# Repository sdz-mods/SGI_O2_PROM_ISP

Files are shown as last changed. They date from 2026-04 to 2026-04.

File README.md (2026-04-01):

# SGI O2 PROM ISP

In-system programmer for the SGI O2 system PROM. It which allows writing/dumping the system PROM via USB. This can be done at any point, with the system on or off.
Mechanically compatible with all O2 CPU modules.

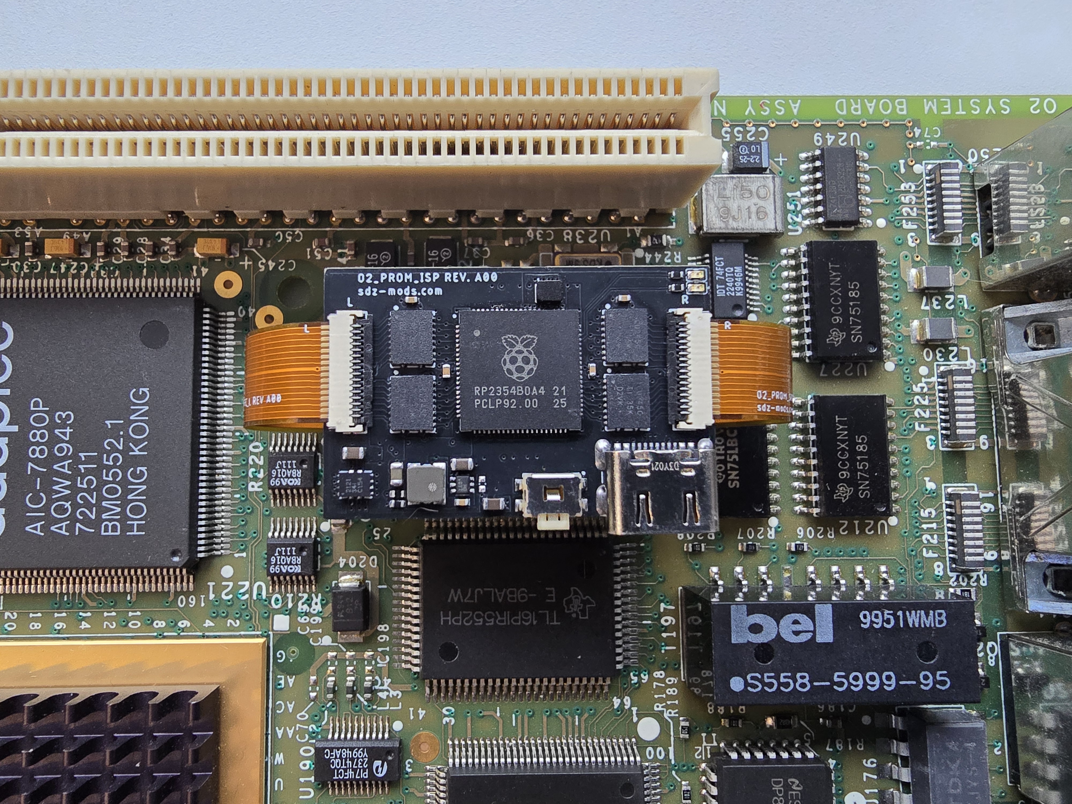
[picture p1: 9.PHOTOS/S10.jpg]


## Installation instructions:

-remove Dallas socket

-remove flash IC

-solder the two FFCs

-solder Dallas socket back

-install Dallas IC

-solder the flash IC to the ISP

-mount ISP on top of Dallas IC, connect the two FFCs.

### Flashing/dumping PROM

```csh
python3 O2_FLASH_PROM.py --port COM38 --flash IP32_418_dump.bin --verify

Opening port: COM38

File : IP32_418_dump.bin  (524,288 bytes)

Flash: 524,288 bytes  |  Chunks: 128 × 4096 bytes

Flashing...

Flashing: [########################################] 100%

Flash complete.

Verifying...

Verifying: [########################################] 100%

Verify passed — flash contents match file.

python3 O2_FLASH_PROM.py --port /dev/ttyUSB0 --dump testdump.bin

Opening port: /dev/ttyUSB0

Dumping 524,288 bytes to: testdump.bin

Dumping: [########################################] 100%

Dump complete. Saved 524,288 bytes to 'testdump.bin'
```

## Contents

1.SCH_BRD - contains editable schematic and board files. Format is Eagle CAD, but they can be imported in other tools, like Kicad.

2.SCH_PDF- schematics in pdf format.

3.P&P - pick and place files

4.BOM

5.GERBER - gerber files

6.FIRMWARE - pre-built firmware to be flashed on the RP2040

7.FIRMWARE_SRC - firmware source code plus support files.

8.HOST_TOOL - host flashing script

9.PHOTOS - installation photos

## Notes

-There is a very high probabilty if you install this and flash a firmware, you won't be able to setenv -p or resetenv from PROM. This isn't related to the ISP, it happens even when swapping the flash ICs between two working motherboards.

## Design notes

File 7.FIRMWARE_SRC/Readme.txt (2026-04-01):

Built with:
cmake version 3.31.5
ninja version 1.12.1
arm-none-eabi-gcc version 14.2.1
Pico SDK 2.2.0

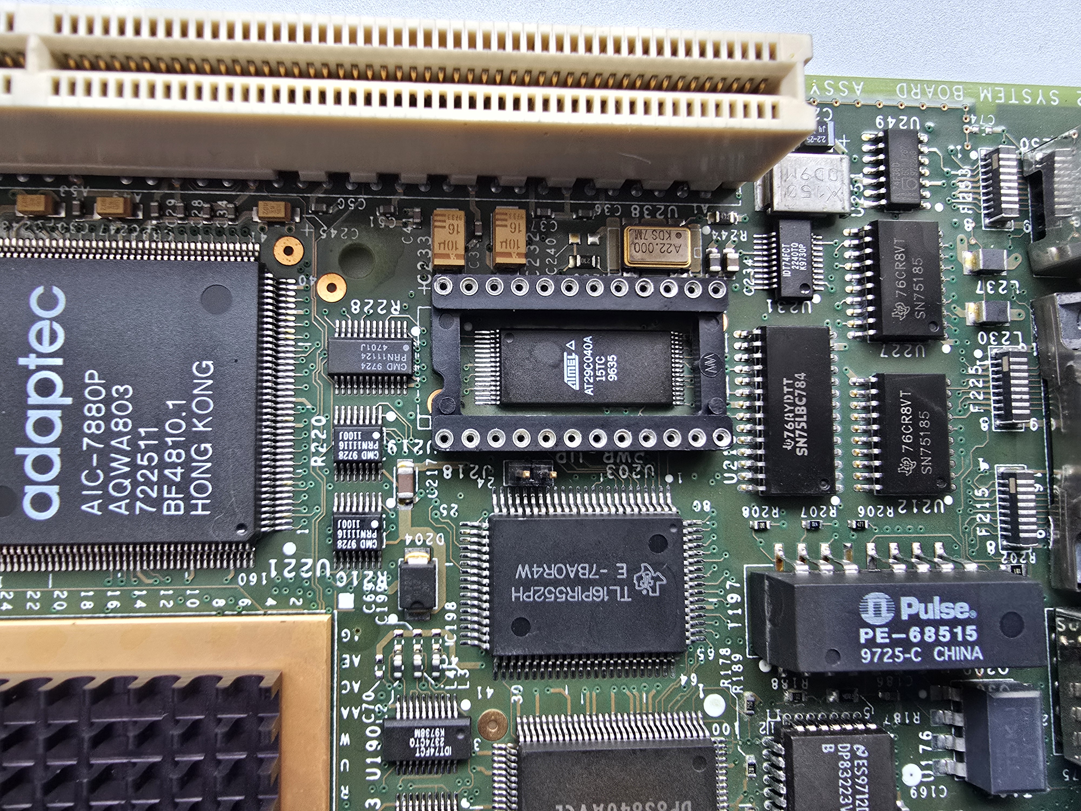
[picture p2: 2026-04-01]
9.PHOTOS/S2.jpg

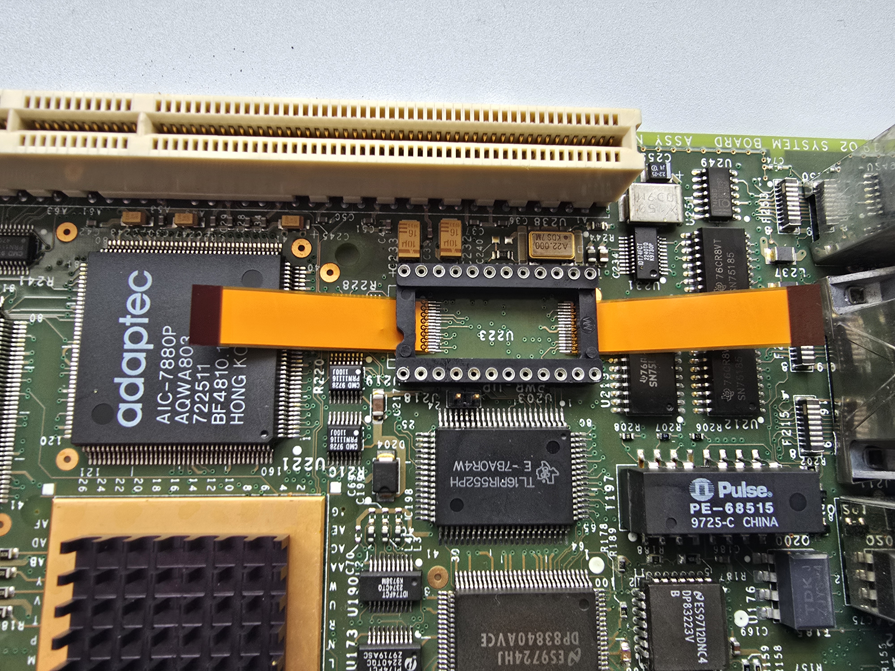
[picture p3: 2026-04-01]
9.PHOTOS/S6.jpg

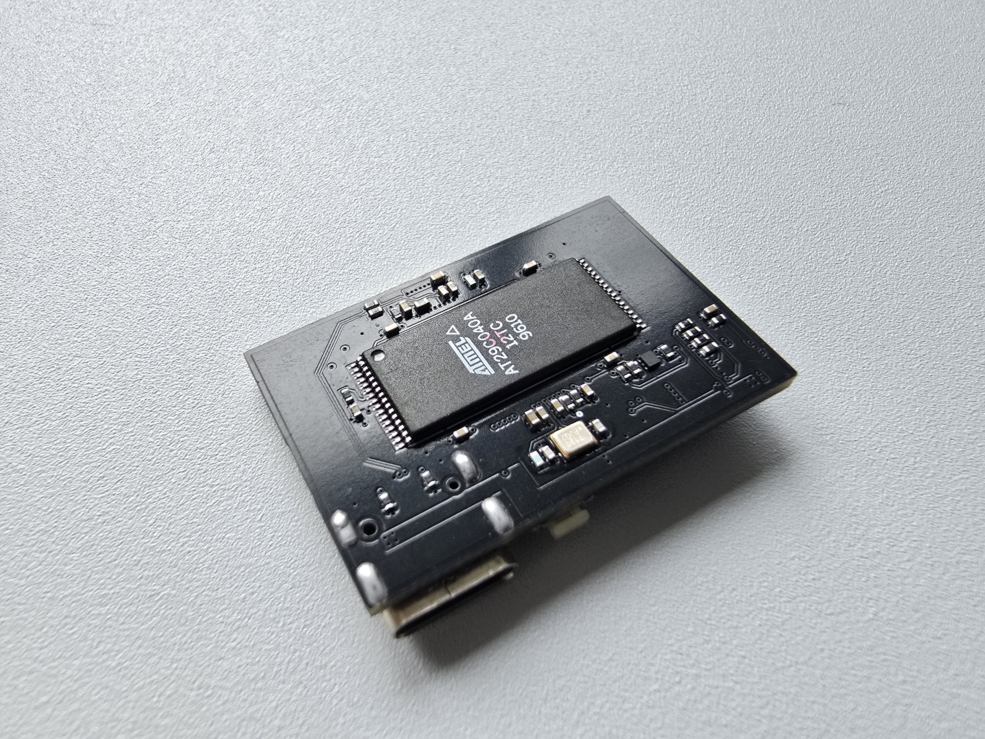
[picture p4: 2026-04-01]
9.PHOTOS/S9.jpg

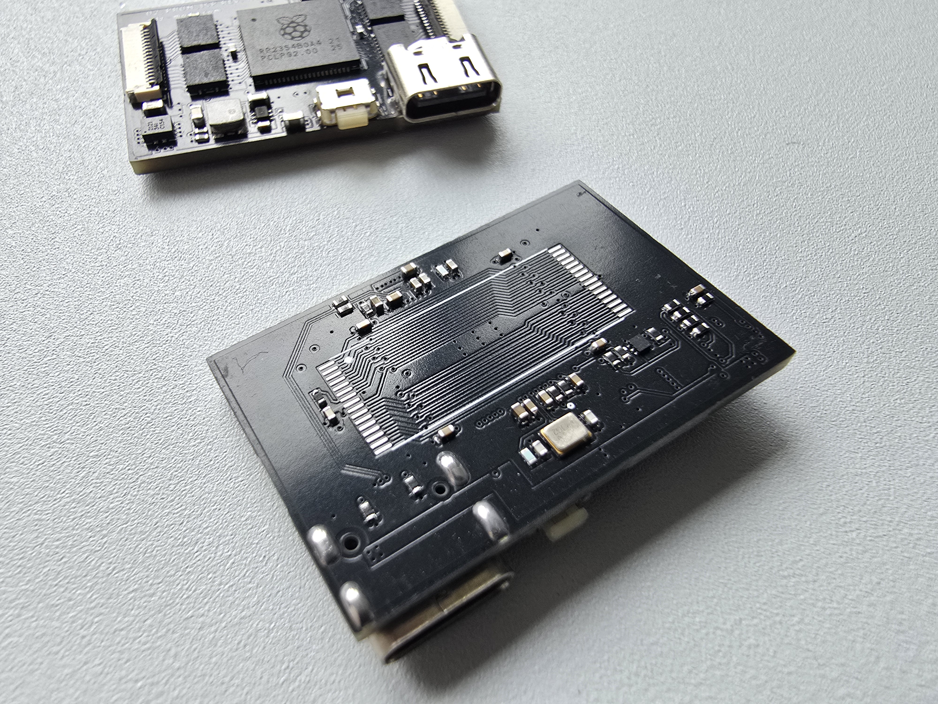
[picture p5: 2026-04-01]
9.PHOTOS/S8.jpg

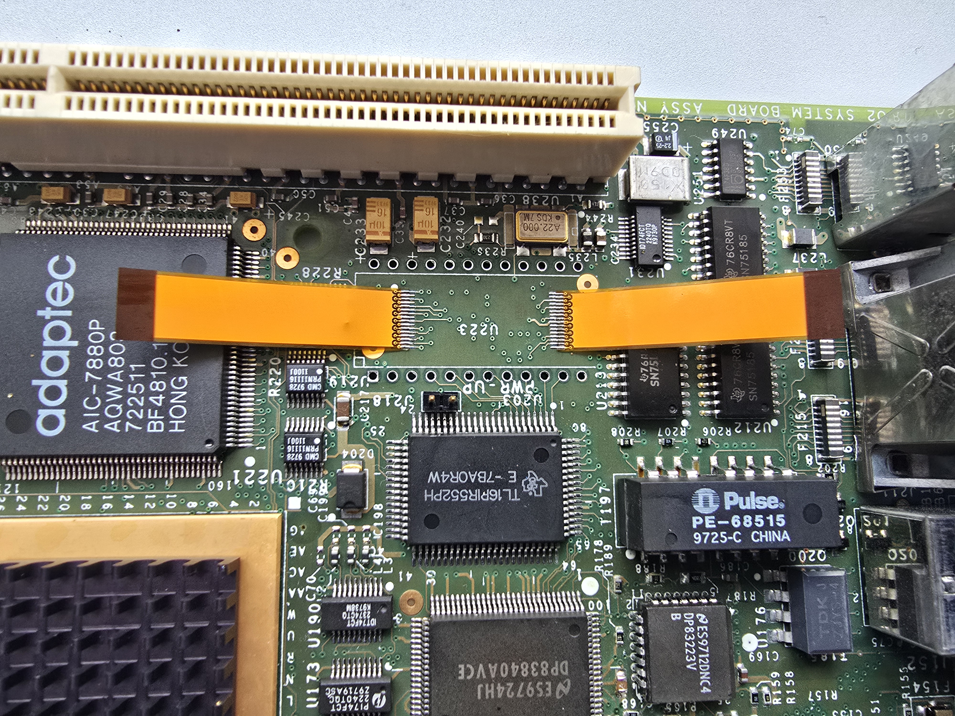
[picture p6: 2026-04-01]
9.PHOTOS/S5.jpg

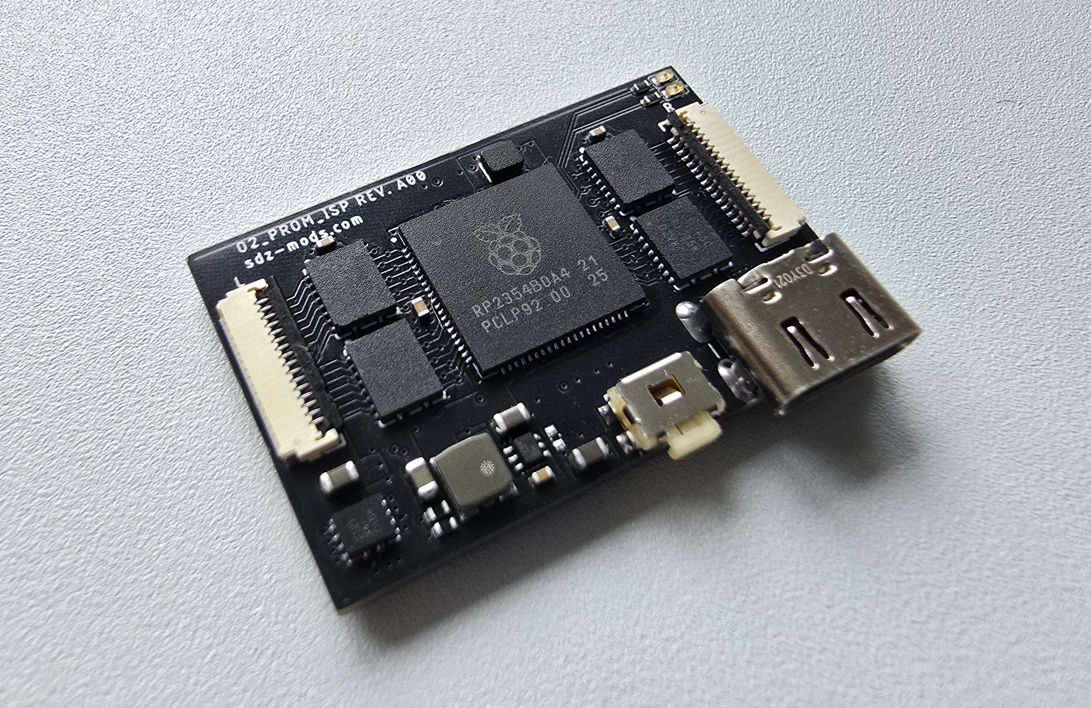
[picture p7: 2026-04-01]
9.PHOTOS/S0.jpg

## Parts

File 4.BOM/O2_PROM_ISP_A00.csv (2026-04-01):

Qty | Value | Device | Package | Parts | Description | CONTACT-RESISTANCE | DATASHEET-URL | DESCRIPTION | HEIGHT | IR | L | MANUFACTURER_NAME | MANUFACTURER_PART_NUMBER | MOUSER_PART_NUMBER | MOUSER_PRICE-STOCK | PACKAGING | PART-NUMBER | PINS | PITCH | TYPE | VALUE | WORKING-VOLTAGE
1 |  | 434353045816 | 434353045816 | S3 | 3.5x4.7 mm SMD J-Bend side push WS-TASU
1 | 10.2kR | RESISTOR0402D | 0402D | R9 | Resistors
16 | 100nF 25V | CAP_CERAMIC0402D | 0402D | C1, C5, C8, C9, C10, C15, C16, C17, C18, C29, C30, C31, C33, C34, C37, C114 | Ceramic Capacitors
8 | 10kR | RESISTOR0402D | 0402D | R2, R11, R12, R13, R14, R15, R16, R100 | Resistors
3 | 10uF 16V | CAP_CERAMIC0603D | 0603D | C2, C3, C4 | Ceramic Capacitors
1 | 18kR | RESISTOR0402D | 0402D | R8 | Resistors
2 | 1kR | RESISTOR0402D | 0402D | R3, R4 | Resistors
2 | 220R | RESISTOR0402D | 0402D | R97, R98 | Resistors
2 | 22R | RESISTOR0402D | 0402D | R5, R6 | Resistors
1 | 22uF 6.3V | CAP_CERAMIC0603D | 0603D | C6 | Ceramic Capacitors
1 | 31.6kR | RESISTOR0402D | 0402D | R1 | Resistors
1 | 33R | RESISTOR0402D | 0402D | R7 | Resistors
2 | 33pF 25V C0G | CAP_CERAMIC0402D | 0402D | C12, C13 | Ceramic Capacitors
5 | 4.7uF 6.3V | CAP_CERAMIC0402D | 0402D | C14, C32, C35, C36, C38 | Ceramic Capacitors
1 | 44.2kR | RESISTOR0402D | 0402D | R105 | Resistors
2 | 5.1kR | RESISTOR0402D | 0402D | R37, R38 | Resistors
1 | 5kR | RESISTOR0402D | 0402D | R10 | Resistors
2 | 687116182122 | 6871XX182122_687116182122 | 687116182122 | J1, J2 | WR-FPC 0.50 mm SMT ZIF Horizontal Dual Contact | 30mOhm | https://www.we-online.com/redexpert/spec/687116182122?ae |  |  | 0.5A | 10mm |  |  |  |  | Tape and Reel | 687116182122 | 16 | 0.5mm | Horizontal | 687116182122 | 50V(AC)
1 | 8Z-12.000MAAJ-T | TXC-8Z-25X20 | TXC-8Z-25X20 | Y2
1 | AOTA-B201610S3R3-101-T | AOTA-B201610S3R3-101-T | 0806 | L2
1 | AP62250Z6-7 | AP62250Z6-7 | SOTFL50P160X60-6N | U5 | Switching Voltage Regulators DCDC Conv HV Buck SOT563 T&R 3K |  |  | Switching Voltage Regulators DCDC Conv HV Buck SOT563 T&R 3K | 0.6mm |  |  | Diodes Inc. | AP62250Z6-7 | 621-AP62250Z6-7 | https://www.mouser.co.uk/ProductDetail/Diodes-Incorporated/AP62250Z6-7?qs=7MVldsJ5UazFBrGnyLje6A%3D%3D
1 | AT29C040A-12TC";AT29C040A-12TC"" | TSOP32_8X20 | U1
1 | DNP | CAP_CERAMIC0402D | 0402D | C7 | Ceramic Capacitors
1 | DX07S016JA3R1500 | DX07S016JA3R1500 | DX07S016JA3R1500 | J4
2 | ORANGE | LED | CHIPLED_0402C | LED5, LED6 | LED
1 | PMDXB600UNEZ | PMDXB600UNEZ | PMDXB600UNEZ | Q3 | PMDXB600UNEZ Hex N-Channel MOSFET, 600 mA, 20 V, 8-Pin DFN1010B-6, SOT1216 Nexperia |  |  | PMDXB600UNEZ Hex N-Channel MOSFET, 600 mA, 20 V, 8-Pin DFN1010B-6, SOT1216 Nexperia | 0.4mm |  |  | Nexperia | PMDXB600UNEZ | 771-PMDXB600UNEZ | https://www.mouser.co.uk/ProductDetail/Nexperia/PMDXB600UNEZ/?qs=gNSudQoqUYA4PlgBT4gR6w%3D%3D
1 | SC1512 | SC1512 | SC1512 | U$35
4 | SN74CBT3245CRGYR | SN74CBT3245CRGYR | VQFN-20 | U9, U10, U11, U12
1 | TPS2121RUX | TPS2121RUX | VQFN-HR-12 | U2
1 | VLS3012HBX-2R2M | VLS3012HBX-2R2M | VLS3012 | L3 | Fixed Inductors 3x3x1.2mm 2.2uH 20% Magnetic Pwr Inductr |  |  | Fixed Inductors 3x3x1.2mm 2.2uH 20% Magnetic Pwr Inductr | mm |  |  | TDK | VLS3012HBX-2R2M | 810-VLS3012HBX-2R2M | https://www.mouser.co.uk/ProductDetail/TDK/VLS3012HBX-2R2M?qs=pfd5qewlna6oSgcfnWnTMg%3D%3D

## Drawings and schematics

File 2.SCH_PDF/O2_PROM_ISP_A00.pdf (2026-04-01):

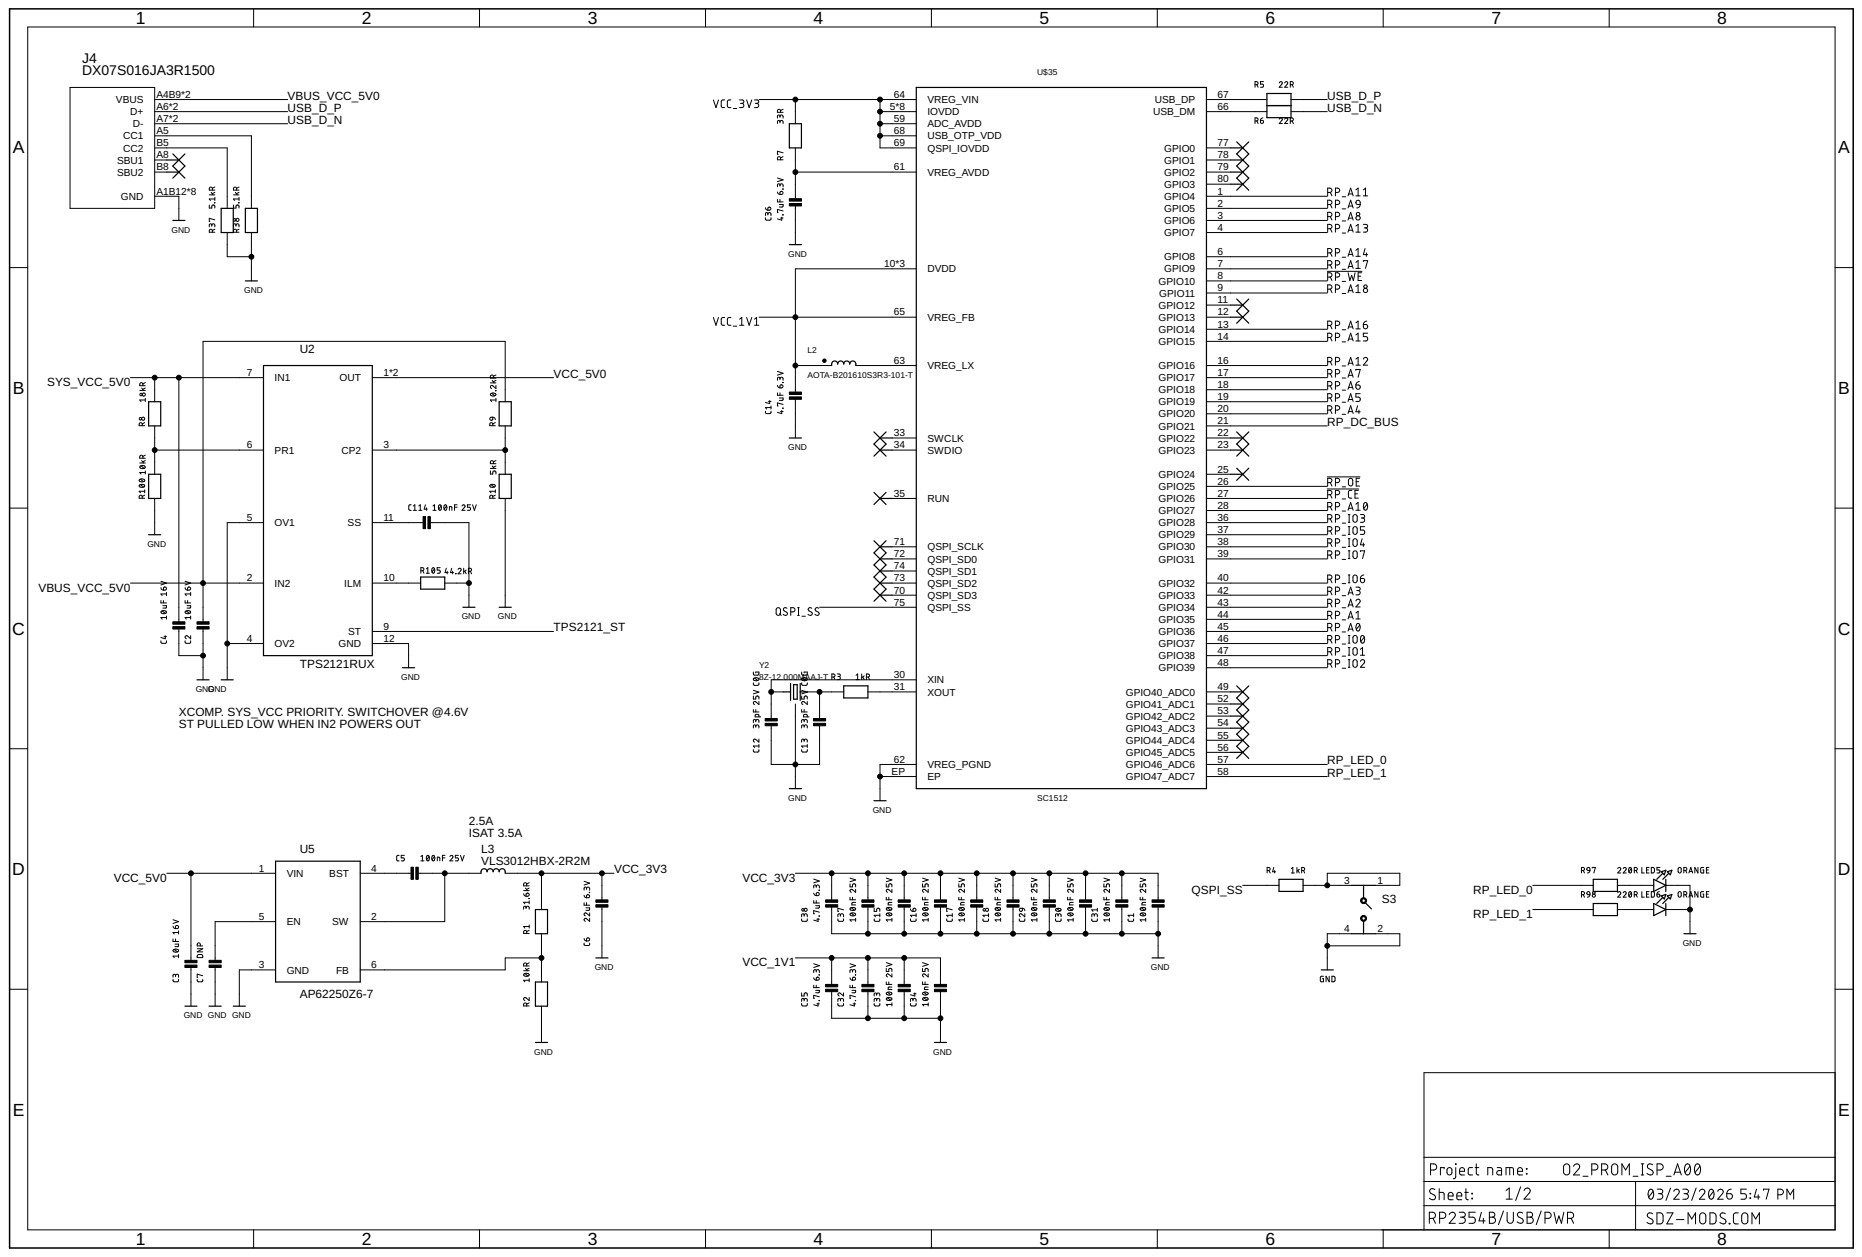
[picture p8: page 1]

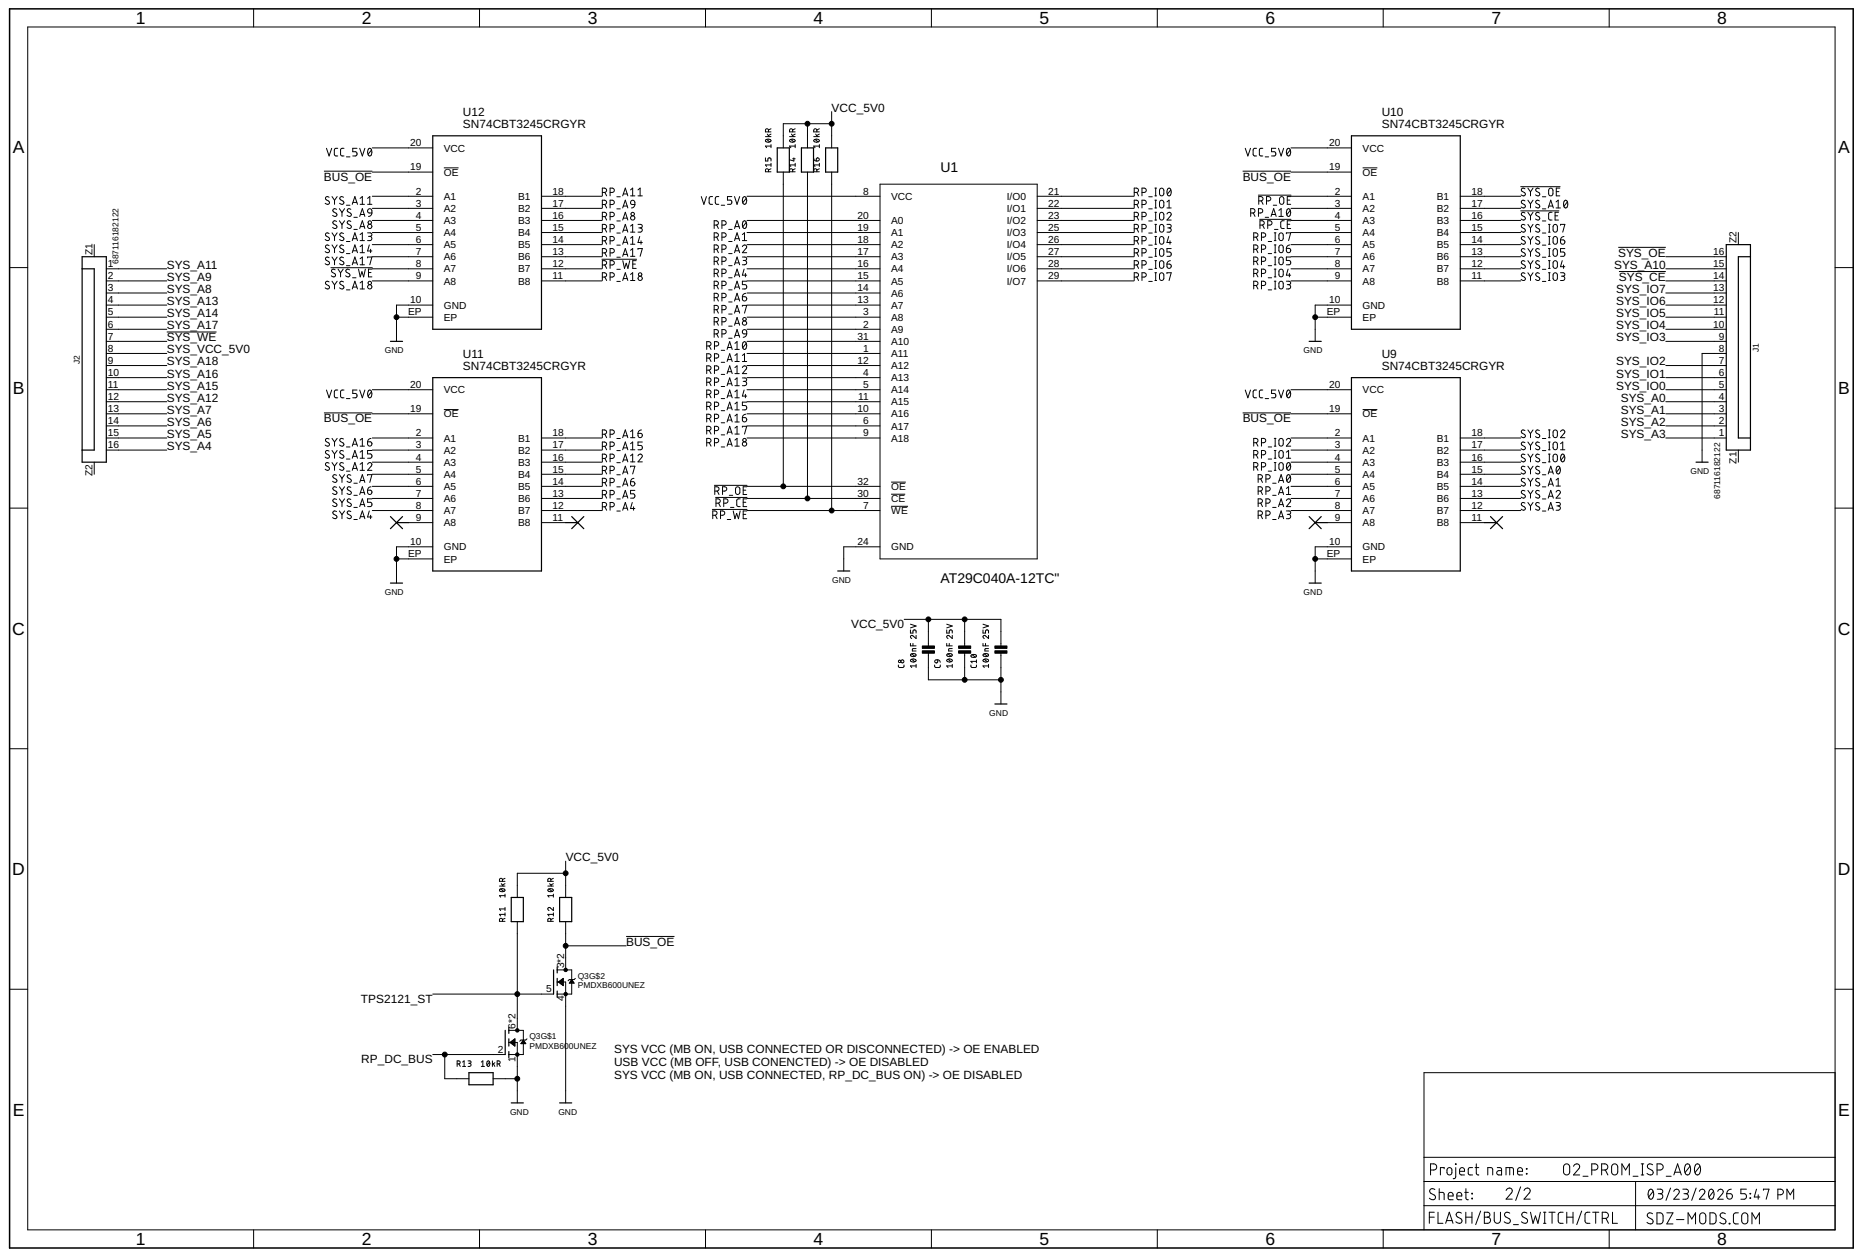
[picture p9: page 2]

VCC_5V0

SYS VCC (MB ON, USB CONNECTED OR DISCONNECTED) -> OE ENABLED
USB VCC (MB OFF, USB CONENCTED) -> OE DISABLED
SYS VCC (MB ON, USB CONNECTED, RP_DC_BUS ON) -> OE DISABLED

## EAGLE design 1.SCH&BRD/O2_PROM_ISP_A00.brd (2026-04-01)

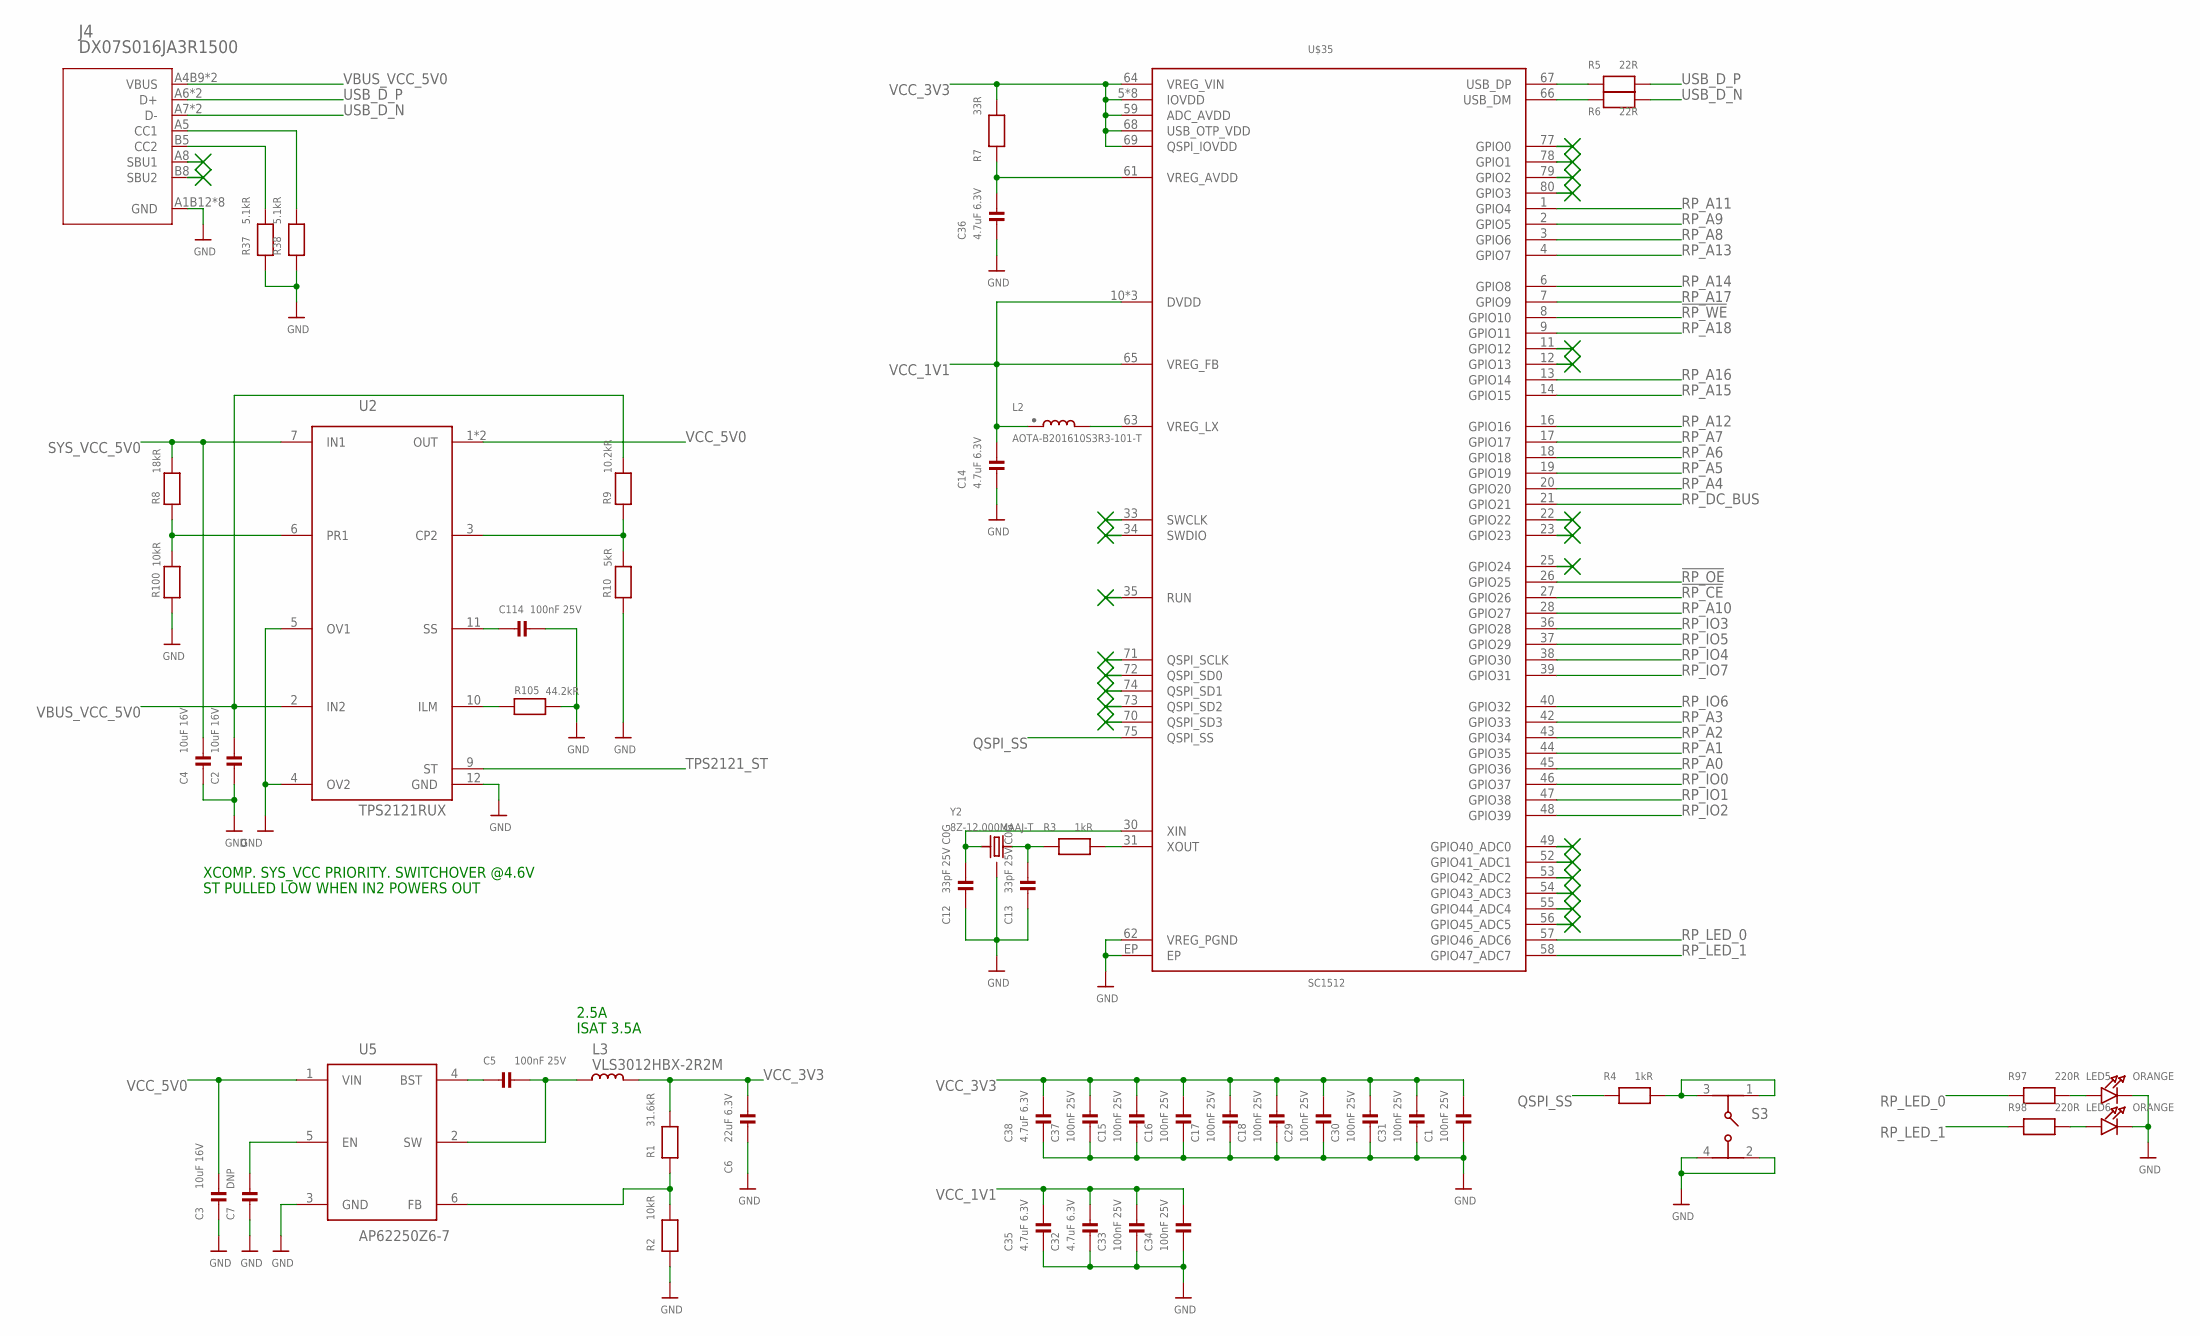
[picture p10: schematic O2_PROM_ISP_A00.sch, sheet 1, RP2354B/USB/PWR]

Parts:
C1, C5, C15, C16, C17, C18, C29, C30, C31, C33, C34, C37, C114: 100nF 25V; 0402D
C2, C3, C4: 10uF 16V; 0603D
C6: 22uF 6.3V; 0603D
C7: DNP; 0402D
C12, C13: 33pF 25V C0G; 0402D
C14, C32, C35, C36, C38: 4.7uF 6.3V; 0402D
J4: DX07S016JA3R1500
L2: AOTA-B201610S3R3-101-T; 0806
L3: VLS3012HBX-2R2M; VLS3012
LED5, LED6: ORANGE; CHIPLED_0402C
R1: 31.6kR; 0402D
R2, R100: 10kR; 0402D
R3, R4: 1kR; 0402D
R5, R6: 22R; 0402D
R7: 33R; 0402D
R8: 18kR; 0402D
R9: 10.2kR; 0402D
R10: 5kR; 0402D
R37, R38: 5.1kR; 0402D
R97, R98: 220R; 0402D
R105: 44.2kR; 0402D
S3: 434353045816
U2: TPS2121RUX; VQFN-HR-12
U5: AP62250Z6-7; SOTFL50P160X60-6N
U$35: SC1512
Y2: 8Z-12.000MAAJ-T; TXC-8Z-25X20

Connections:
!RP_CE: U$35.27 (GPIO26); also elsewhere on the board
!RP_OE: U$35.26 (GPIO25); also elsewhere on the board
!RP_WE: U$35.8 (GPIO10); also elsewhere on the board
GND: C1.3, C2.2, C3.2, C4.2, C6.2, C7.4, C12.3, C13.3, C14.3, C15.3, C16.3, C17.3, C18.3, C29.3, C30.3, C31.3, C32.3, C33.3, C34.3, C35.3, C36.3, C37.3, C38.3, C114.3, J4.A1B12 (GND), J4.A12/B1 (GND), J4.MH1 (GND), J4.MH2 (GND), J4.MH3 (GND), J4.MH4 (GND), J4.MP1 (GND), J4.MP2 (GND), LED5.4 (C), LED6.4 (C), R2.4 (2), R10.3 (1), R37.3 (1), R38.3 (1), R100.3 (1), R105.4 (2), S3.2 (4), S3.4 (2), U2.4 (OV2), U2.5 (OV1), U2.12 (GND), U5.3 (GND), U$35.62 (VREG_PGND), U$35.EP, Y2.2 (GND), Y2.4 (GND); also elsewhere on the board
unnamed: J4.A5 (CC1), R38.4 (2)
unnamed: R9.3 (1), R10.4 (2), U2.3 (CP2)
unnamed: J4.B5 (CC2), R37.4 (2)
unnamed: LED5.3 (A), R97.3 (1)
unnamed: LED6.3 (A), R98.3 (1)
unnamed: C13.4, R3.3 (1), Y2.3 (2)
unnamed: C12.4, U$35.30 (XIN), Y2.1
unnamed: R3.4 (2), U$35.31 (XOUT)
unnamed: R4.4 (2), S3.1 (3), S3.3 (1)
unnamed: L2.2, U$35.63 (VREG_LX)
unnamed: C5.4, U5.4 (BST)
unnamed: C5.3, L3.1 (3), U5.2 (SW)
unnamed: R1.4 (2), R2.3 (1), U5.6 (FB)
unnamed: C7.3, U5.5 (EN)
unnamed: C36.4, R7.4 (2), U$35.61 (VREG_AVDD)
unnamed: C114.4, U2.11 (SS)
unnamed: R105.3 (1), U2.10 (ILM)
unnamed: R8.3 (1), R100.4 (2), U2.6 (PR1)
QSPI_SS: R4.3 (1), U$35.75 (QSPI_SS)
RP_A0: U$35.45 (GPIO36); also elsewhere on the board
RP_A1: U$35.44 (GPIO35); also elsewhere on the board
RP_A2: U$35.43 (GPIO34); also elsewhere on the board
RP_A3: U$35.42 (GPIO33); also elsewhere on the board
RP_A4: U$35.20 (GPIO20); also elsewhere on the board
RP_A5: U$35.19 (GPIO19); also elsewhere on the board
RP_A6: U$35.18 (GPIO18); also elsewhere on the board
RP_A7: U$35.17 (GPIO17); also elsewhere on the board
RP_A8: U$35.3 (GPIO6); also elsewhere on the board
RP_A9: U$35.2 (GPIO5); also elsewhere on the board
RP_A10: U$35.28 (GPIO27); also elsewhere on the board
RP_A11: U$35.1 (GPIO4); also elsewhere on the board
RP_A12: U$35.16 (GPIO16); also elsewhere on the board
RP_A13: U$35.4 (GPIO7); also elsewhere on the board
RP_A14: U$35.6 (GPIO8); also elsewhere on the board
RP_A15: U$35.14 (GPIO15); also elsewhere on the board
RP_A16: U$35.13 (GPIO14); also elsewhere on the board
RP_A17: U$35.7 (GPIO9); also elsewhere on the board
RP_A18: U$35.9 (GPIO11); also elsewhere on the board
RP_DC_BUS: U$35.21 (GPIO21); also elsewhere on the board
RP_IO0: U$35.46 (GPIO37); also elsewhere on the board
RP_IO1: U$35.47 (GPIO38); also elsewhere on the board
RP_IO2: U$35.48 (GPIO39); also elsewhere on the board
RP_IO3: U$35.36 (GPIO28); also elsewhere on the board
RP_IO4: U$35.38 (GPIO30); also elsewhere on the board
RP_IO5: U$35.37 (GPIO29); also elsewhere on the board
RP_IO6: U$35.40 (GPIO32); also elsewhere on the board
RP_IO7: U$35.39 (GPIO31); also elsewhere on the board
RP_LED_0: R97.4 (2), U$35.57 (GPIO46_ADC6)
RP_LED_1: R98.4 (2), U$35.58 (GPIO47_ADC7)
SYS_VCC_5V0: C4.1, R8.4 (2), U2.7 (IN1); also elsewhere on the board
TPS2121_ST: U2.9 (ST); also elsewhere on the board
USB_D_C_N: R6.3 (1), U$35.66 (USB_DM)
USB_D_C_P: R5.3 (1), U$35.67 (USB_DP)
USB_D_N: J4.A7 (D-), J4.B7 (D-), R6.4 (2)
USB_D_P: J4.A6 (D+), J4.B6 (D+), R5.4 (2)
VBUS_VCC_5V0: C2.1, J4.A4B9 (VBUS), J4.B4A9 (VBUS), R9.4 (2), U2.2 (IN2)
VCC_1V1: C14.4, C32.4, C33.4, C34.4, C35.4, L2.1, U$35.10 (DVDD), U$35.32 (DVDD), U$35.51 (DVDD), U$35.65 (VREG_FB)
VCC_3V3: C1.4, C6.1, C15.4, C16.4, C17.4, C18.4, C29.4, C30.4, C31.4, C37.4, C38.4, L3.2 (4), R1.3 (1), R7.3 (1), U$35.5 (IOVDD), U$35.15 (IOVDD), U$35.24 (IOVDD), U$35.29 (IOVDD), U$35.41 (IOVDD), U$35.50 (IOVDD), U$35.59 (ADC_AVDD), U$35.60 (IOVDD), U$35.64 (VREG_VIN), U$35.68 (USB_OTP_VDD), U$35.69 (QSPI_IOVDD), U$35.76 (IOVDD)
VCC_5V0: C3.1, U2.1 (OUT), U2.8 (OUT), U5.1 (VIN); also elsewhere on the board

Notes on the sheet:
2.5A
ISAT 3.5A
XCOMP. SYS_VCC PRIORITY. SWITCHOVER @4.6V
ST PULLED LOW WHEN IN2 POWERS OUT

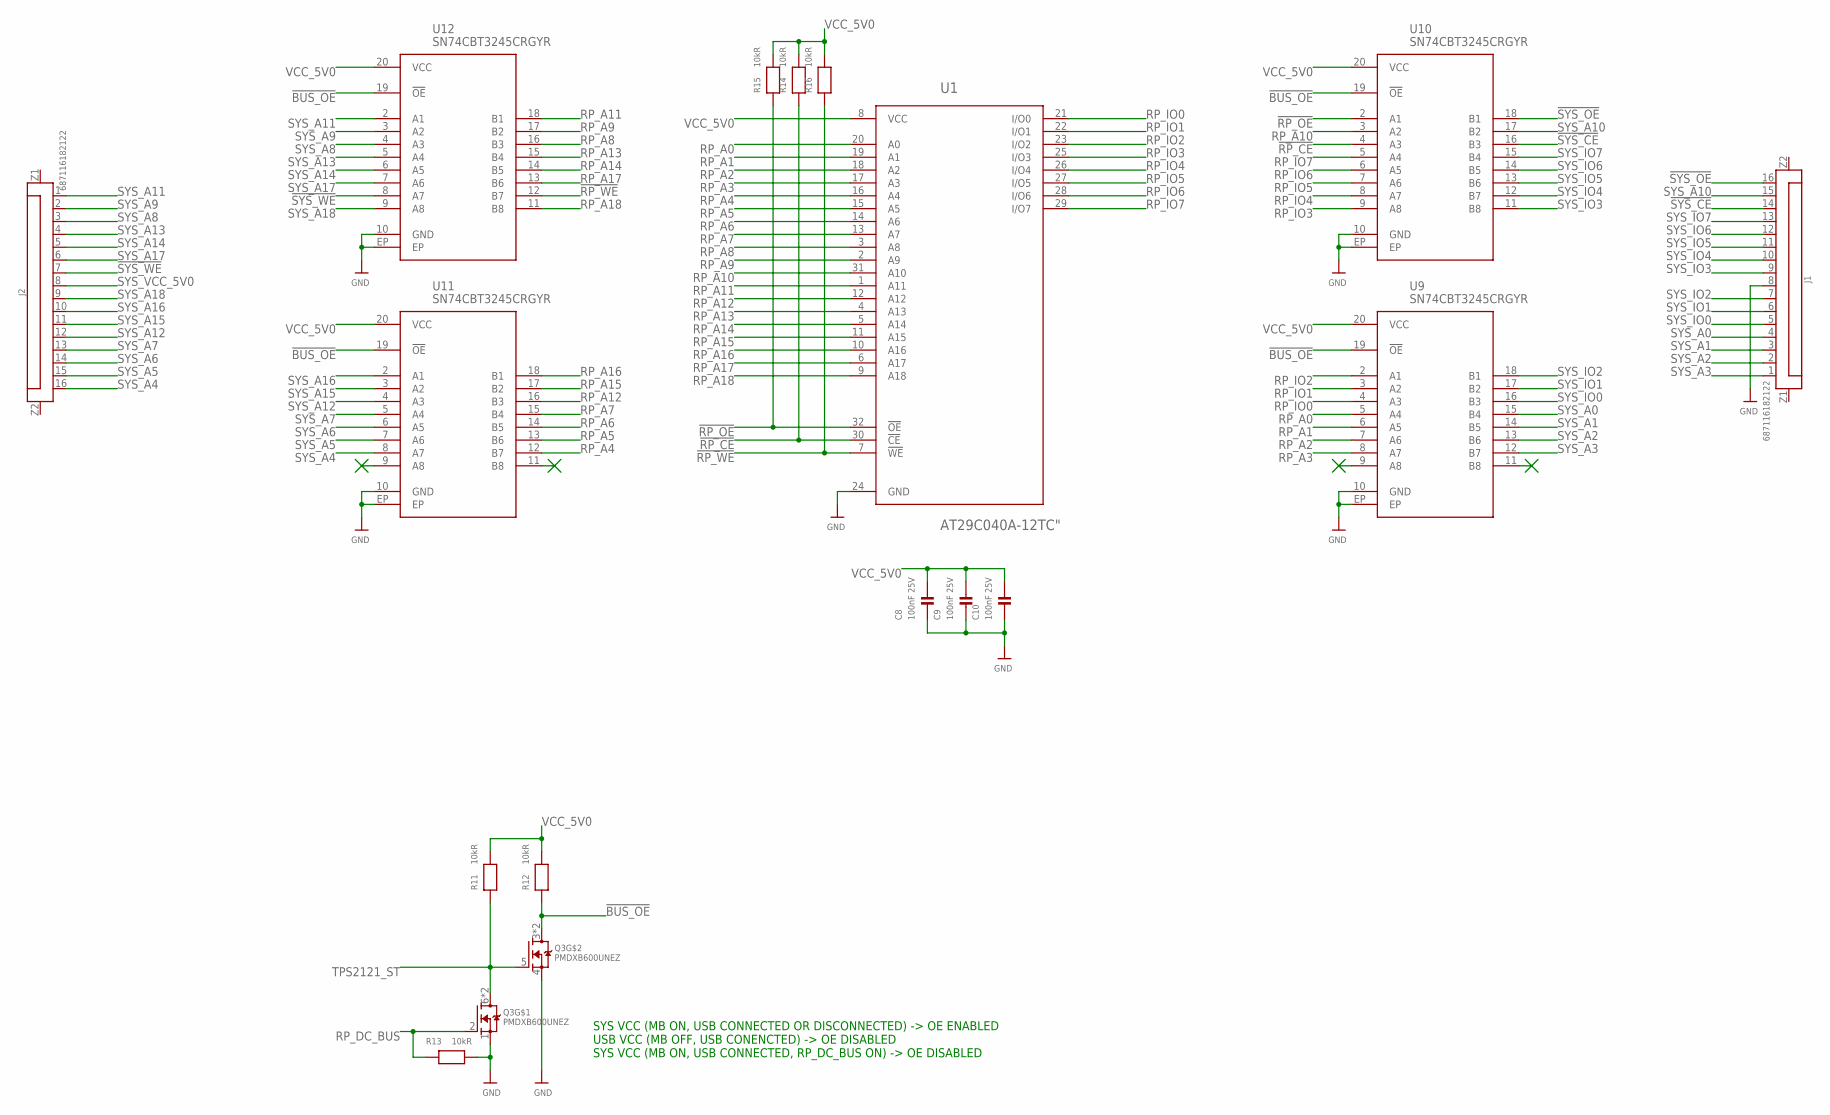
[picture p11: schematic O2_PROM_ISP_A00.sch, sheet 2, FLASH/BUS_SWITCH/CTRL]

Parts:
C8, C9, C10: 100nF 25V; 0402D
J1, J2: 687116182122
Q3: PMDXB600UNEZ
R11, R12, R13, R14, R15, R16: 10kR; 0402D
U1: AT29C040A-12TC"; TSOP32_8X20
U9, U10, U11, U12: SN74CBT3245CRGYR; VQFN-20

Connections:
!BUS_OE: Q3.3 (D), Q3.8 (D), R12.4 (2), U9.19 (!OE), U10.19 (!OE), U11.19 (!OE), U12.19 (!OE)
!RP_CE: R14.4 (2), U1.30 (!CE), U10.4 (A3); also elsewhere on the board
!RP_OE: R15.4 (2), U1.32 (!OE), U10.2 (A1); also elsewhere on the board
!RP_WE: R16.4 (2), U1.7 (!WE), U12.12 (B7); also elsewhere on the board
!SYS_CE: J1.14, U10.16 (B3)
!SYS_OE: J1.16, U10.18 (B1)
!SYS_WE: J2.7, U12.8 (A7)
GND: C8.3, C9.3, C10.3, J1.8, Q3.1 (S), Q3.4 (S), R13.3 (1), U1.24 (GND), U9.10 (GND), U9.EP, U10.10 (GND), U10.EP, U11.10 (GND), U11.EP, U12.10 (GND), U12.EP; also elsewhere on the board
RP_A0: U1.20 (A0), U9.5 (A4); also elsewhere on the board
RP_A1: U1.19 (A1), U9.6 (A5); also elsewhere on the board
RP_A2: U1.18 (A2), U9.7 (A6); also elsewhere on the board
RP_A3: U1.17 (A3), U9.8 (A7); also elsewhere on the board
RP_A4: U1.16 (A4), U11.12 (B7); also elsewhere on the board
RP_A5: U1.15 (A5), U11.13 (B6); also elsewhere on the board
RP_A6: U1.14 (A6), U11.14 (B5); also elsewhere on the board
RP_A7: U1.13 (A7), U11.15 (B4); also elsewhere on the board
RP_A8: U1.3 (A8), U12.16 (B3); also elsewhere on the board
RP_A9: U1.2 (A9), U12.17 (B2); also elsewhere on the board
RP_A10: U1.31 (A10), U10.3 (A2); also elsewhere on the board
RP_A11: U1.1 (A11), U12.18 (B1); also elsewhere on the board
RP_A12: U1.12 (A12), U11.16 (B3); also elsewhere on the board
RP_A13: U1.4 (A13), U12.15 (B4); also elsewhere on the board
RP_A14: U1.5 (A14), U12.14 (B5); also elsewhere on the board
RP_A15: U1.11 (A15), U11.17 (B2); also elsewhere on the board
RP_A16: U1.10 (A16), U11.18 (B1); also elsewhere on the board
RP_A17: U1.6 (A17), U12.13 (B6); also elsewhere on the board
RP_A18: U1.9 (A18), U12.11 (B8); also elsewhere on the board
RP_DC_BUS: Q3.2 (G), R13.4 (2); also elsewhere on the board
RP_IO0: U1.21 (I/O0), U9.4 (A3); also elsewhere on the board
RP_IO1: U1.22 (I/O1), U9.3 (A2); also elsewhere on the board
RP_IO2: U1.23 (I/O2), U9.2 (A1); also elsewhere on the board
RP_IO3: U1.25 (I/O3), U10.9 (A8); also elsewhere on the board
RP_IO4: U1.26 (I/O4), U10.8 (A7); also elsewhere on the board
RP_IO5: U1.27 (I/O5), U10.7 (A6); also elsewhere on the board
RP_IO6: U1.28 (I/O6), U10.6 (A5); also elsewhere on the board
RP_IO7: U1.29 (I/O7), U10.5 (A4); also elsewhere on the board
SYS_A0: J1.4, U9.15 (B4)
SYS_A1: J1.3, U9.14 (B5)
SYS_A2: J1.2, U9.13 (B6)
SYS_A3: J1.1, U9.12 (B7)
SYS_A4: J2.16, U11.8 (A7)
SYS_A5: J2.15, U11.7 (A6)
SYS_A6: J2.14, U11.6 (A5)
SYS_A7: J2.13, U11.5 (A4)
SYS_A8: J2.3, U12.4 (A3)
SYS_A9: J2.2, U12.3 (A2)
SYS_A10: J1.15, U10.17 (B2)
SYS_A11: J2.1, U12.2 (A1)
SYS_A12: J2.12, U11.4 (A3)
SYS_A13: J2.4, U12.5 (A4)
SYS_A14: J2.5, U12.6 (A5)
SYS_A15: J2.11, U11.3 (A2)
SYS_A16: J2.10, U11.2 (A1)
SYS_A17: J2.6, U12.7 (A6)
SYS_A18: J2.9, U12.9 (A8)
SYS_IO0: J1.5, U9.16 (B3)
SYS_IO1: J1.6, U9.17 (B2)
SYS_IO2: J1.7, U9.18 (B1)
SYS_IO3: J1.9, U10.11 (B8)
SYS_IO4: J1.10, U10.12 (B7)
SYS_IO5: J1.11, U10.13 (B6)
SYS_IO6: J1.12, U10.14 (B5)
SYS_IO7: J1.13, U10.15 (B4)
SYS_VCC_5V0: J2.8; also elsewhere on the board
TPS2121_ST: Q3.5 (G), Q3.6 (D), Q3.7 (D), R11.4 (2); also elsewhere on the board
VCC_5V0: C8.4, C9.4, C10.4, R11.3 (1), R12.3 (1), R14.3 (1), R15.3 (1), R16.3 (1), U1.8 (VCC), U9.20 (VCC), U10.20 (VCC), U11.20 (VCC), U12.20 (VCC); also elsewhere on the board

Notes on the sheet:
SYS VCC (MB ON, USB CONNECTED OR DISCONNECTED) -> OE ENABLED USB VCC (MB OFF, USB CONENCTED) -> OE DISABLED SYS VCC (MB ON, USB CONNECTED, RP_DC_BUS ON) -> OE DISABLED

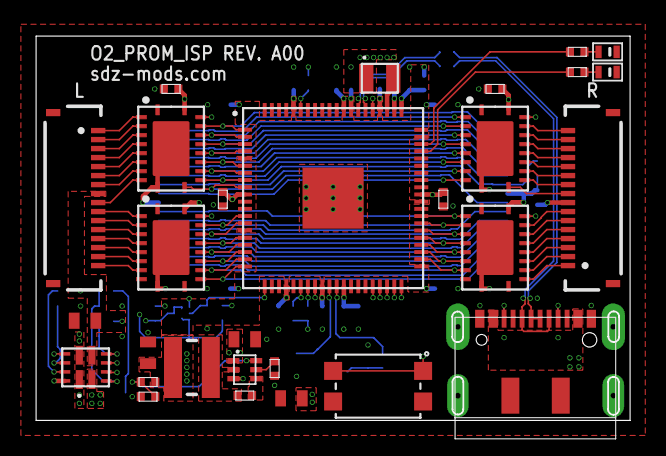
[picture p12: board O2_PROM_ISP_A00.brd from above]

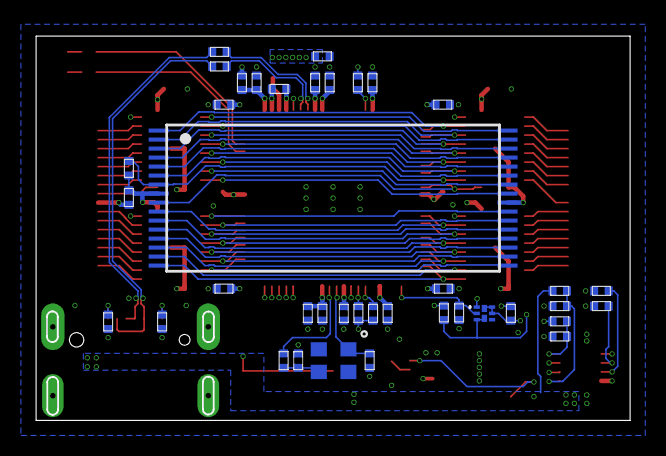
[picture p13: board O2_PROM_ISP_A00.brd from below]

Board: 4 copper layers, 33.0 x 21.4 mm, 68 parts (39 on the bottom side), 94 nets.

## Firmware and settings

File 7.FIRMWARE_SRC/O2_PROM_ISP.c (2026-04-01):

/*
 * O2 PROM ISP - Firmware for RP2354B
 *
 * Programs/reads AT29C040A parallel flash via USB CDC.
 * Protocol: text commands with binary data payloads.
 *
 * Commands (host -> MCU, newline terminated):
 *   VER               -> "OK A00\n"
 *   BOOT              -> reboot to BOOTSEL (UF2 mode)
 *   FLASH <size>\n    -> "OK\n", then receive <size> bytes in CHUNK_SIZE
 *                        chunks, each ACK'd with "ACK\n"; finish: "DONE\n"
 *   VERIFY <size>\n   -> same as FLASH but reads back and compares instead
 *                        of writing; mismatch reports "ERR <offset>\n"
 *   DUMP\n            -> "SIZE 524288\n", then sends binary in CHUNK_SIZE
 *                        chunks waiting for "ACK\n" after each; finish: "DONE\n"
 *
 * Flash write note:
 *   Each page write is preceded by a 3-byte fast SDP unlock sequence
 *   (AA→5555, 55→2AAA, A0→5555) required by this chip variant.
 *   All flash bus GPIOs are high-Z when idle; they are driven only during
 *   an active flash_bus_acquire / flash_bus_release window.
 */

#include <stdio.h>
#include <string.h>
#include <stdlib.h>
#include "pico/stdlib.h"
#include "pico/bootrom.h"
#include "hardware/gpio.h"

/* -------------------------------------------------------------------------
 * Constants
 * ---------------------------------------------------------------------- */

#define FIRMWARE_VERSION    "A00"
#define FLASH_SIZE          (512u * 1024u)  /* AT29C040A: 512 KB */
#define PAGE_SIZE           256u            /* AT29C040A page size */
#define CHUNK_SIZE          4096u           /* 16 pages per USB chunk */
#define CMD_BUF_SIZE        64u

/* -------------------------------------------------------------------------
 * Pin definitions
 * ---------------------------------------------------------------------- */

#define DC_BUS_PIN  21u   /* High while MCU owns the flash bus */
#define WE_N_PIN    10u
#define OE_N_PIN    25u
#define CE_N_PIN    26u
#define LED0_PIN    46u   /* On when firmware is running */
#define LED1_PIN    47u   /* 2 Hz heartbeat */

/*
 * Address bus: A0..A18 -> GPIO
 *   A0 =36, A1=35, A2=34, A3=33, A4=20, A5=19, A6=18, A7=17,
 *   A8 = 6, A9= 5, A10=27, A11=4, A12=16, A13=7, A14=8, A15=15,
 *   A16=14, A17=9, A18=11
 */
static const uint8_t ADDR_PINS[19] = {
    36, 35, 34, 33, 20, 19, 18, 17,   /* A0-A7  */
     6,  5, 27,  4, 16,  7,  8, 15,   /* A8-A15 */
    14,  9, 11                         /* A16-A18 */
};

/*
 * Data bus: D0..D7 -> GPIO
 *   D0=37, D1=38, D2=39, D3=28, D4=30, D5=29, D6=32, D7=31
 */
static const uint8_t DATA_PINS[8] = {
    37, 38, 39, 28, 30, 29, 32, 31
};

/* -------------------------------------------------------------------------
 * Heartbeat state
 * ---------------------------------------------------------------------- */

static absolute_time_t led1_next;
static bool led1_state = false;

static void heartbeat_update(void) {
    if (time_reached(led1_next)) {
        led1_state = !led1_state;
        gpio_put(LED1_PIN, led1_state);
        led1_next = make_timeout_time_ms(500); /* 2 toggles/s = 1 Hz */
    }
}

/* -------------------------------------------------------------------------
 * Flash bus helpers
 * ---------------------------------------------------------------------- */

static void flash_set_address(uint32_t addr) {
    for (int i = 0; i < 19; i++) {
        gpio_put(ADDR_PINS[i], (addr >> i) & 1u);
    }
}

static void flash_data_dir_out(void) {
    for (int i = 0; i < 8; i++) {
        gpio_set_dir(DATA_PINS[i], GPIO_OUT);
    }
}

static void flash_data_dir_in(void) {
    for (int i = 0; i < 8; i++) {
        gpio_set_dir(DATA_PINS[i], GPIO_IN);
        gpio_disable_pulls(DATA_PINS[i]);
    }
}

static void flash_set_data_out(uint8_t data) {
    for (int i = 0; i < 8; i++) {
        gpio_put(DATA_PINS[i], (data >> i) & 1u);
    }
}

static uint8_t flash_get_data_in(void) {
    uint8_t data = 0;
    for (int i = 0; i < 8; i++) {
        if (gpio_get(DATA_PINS[i])) {
            data |= (uint8_t)(1u << i);
        }
    }
    return data;
}

/* Acquire flash bus: drive all bus pins as outputs, assert DC_BUS. */
static void flash_bus_acquire(void) {
    /* Address pins: output, start at 0 */
    for (int i = 0; i < 19; i++) {
        gpio_set_dir(ADDR_PINS[i], GPIO_OUT);
        gpio_put(ADDR_PINS[i], 0);
    }
    /* Control lines: output, deasserted (active-low → idle = 1) */
    gpio_set_dir(WE_N_PIN, GPIO_OUT); gpio_put(WE_N_PIN, 1);
    gpio_set_dir(OE_N_PIN, GPIO_OUT); gpio_put(OE_N_PIN, 1);
    gpio_set_dir(CE_N_PIN, GPIO_OUT); gpio_put(CE_N_PIN, 1);
    /* Data bus stays input until a write needs it (flash_data_dir_out) */
    gpio_put(DC_BUS_PIN, 1);
    sleep_us(10);
}

/* Release flash bus: high-Z all flash bus GPIOs, then drop DC_BUS. */
static void flash_bus_release(void) {
    /* Deassert controls before going high-Z */
    gpio_put(WE_N_PIN, 1);
    gpio_put(OE_N_PIN, 1);
    gpio_put(CE_N_PIN, 1);
    /* High-Z address bus */
    for (int i = 0; i < 19; i++) {
        gpio_set_dir(ADDR_PINS[i], GPIO_IN);
        gpio_disable_pulls(ADDR_PINS[i]);
    }
    /* High-Z data bus */
    for (int i = 0; i < 8; i++) {
        gpio_set_dir(DATA_PINS[i], GPIO_IN);
        gpio_disable_pulls(DATA_PINS[i]);
    }
    /* High-Z control lines (external pull-ups keep them inactive) */
    gpio_set_dir(WE_N_PIN, GPIO_IN); gpio_disable_pulls(WE_N_PIN);
    gpio_set_dir(OE_N_PIN, GPIO_IN); gpio_disable_pulls(OE_N_PIN);
    gpio_set_dir(CE_N_PIN, GPIO_IN); gpio_disable_pulls(CE_N_PIN);
    /* Drop DC_BUS — system bus may now reconnect to the flash */
    gpio_put(DC_BUS_PIN, 0);
}

/* -------------------------------------------------------------------------
 * Flash operations
 * ---------------------------------------------------------------------- */

/*
 * Read one byte at a given address.
 * Data pins must already be set to input (flash_data_dir_in).
 */
static uint8_t flash_read_byte(uint32_t addr) {
    flash_set_address(addr);
    gpio_put(CE_N_PIN, 0);
    gpio_put(OE_N_PIN, 0);
    sleep_us(1);            /* tRC >= 70 ns; 1 µs gives ample margin */
    uint8_t data = flash_get_data_in();
    gpio_put(OE_N_PIN, 1);
    gpio_put(CE_N_PIN, 1);
    sleep_us(1);
    return data;
}

/*
 * Write one byte as a single-byte page write.
 * Used for SDP command sequences.
 * Data pins must already be set to output (flash_data_dir_out).
 */
static void flash_write_single_byte(uint32_t addr, uint8_t data) {
    flash_set_address(addr);
    flash_set_data_out(data);
    gpio_put(CE_N_PIN, 0);
    sleep_us(1);
    gpio_put(WE_N_PIN, 0);
    sleep_us(1);    /* tWP >= 100 ns */
    gpio_put(WE_N_PIN, 1);
    sleep_us(1);
    gpio_put(CE_N_PIN, 1);
    sleep_ms(12);   /* tWC max = 10 ms; 12 ms for margin */
}

/*
 * Per-page SDP unlock sequence — must be called immediately before
 * each flash_write_page() call.
 *
 * Three fast CE# cycles (only µs gaps between bytes — no tWC).
 * This is the "Byte/Page Program" software command the chip recognises
 * as a per-write SDP bypass.
 *
 * Data pins must already be set to output.
 */
static void flash_unlock_for_write(void) {
    /* AA → 5555h */
    flash_set_address(0x5555u); flash_set_data_out(0xAAu);
    gpio_put(CE_N_PIN, 0); sleep_us(1);
    gpio_put(WE_N_PIN, 0); sleep_us(1); gpio_put(WE_N_PIN, 1); sleep_us(1);
    gpio_put(CE_N_PIN, 1); sleep_us(2);
    /* 55h → 2AAAh */
    flash_set_address(0x2AAAu); flash_set_data_out(0x55u);
    gpio_put(CE_N_PIN, 0); sleep_us(1);
    gpio_put(WE_N_PIN, 0); sleep_us(1); gpio_put(WE_N_PIN, 1); sleep_us(1);
    gpio_put(CE_N_PIN, 1); sleep_us(2);
    /* A0h → 5555h (byte/page program command) */
    flash_set_address(0x5555u); flash_set_data_out(0xA0u);
    gpio_put(CE_N_PIN, 0); sleep_us(1);
    gpio_put(WE_N_PIN, 0); sleep_us(1); gpio_put(WE_N_PIN, 1); sleep_us(1);
    gpio_put(CE_N_PIN, 1); sleep_us(2);
}

/*
 * Write one 256-byte page to the AT29C040A.
 *
 * page_num selects which 256-byte page (0 .. 2047).
 *
 * Sends the 3-byte fast SDP unlock (flash_unlock_for_write) first, then
 * holds CE_N low while loading all 256 bytes with WE_N pulses.
 * CE_N rising edge starts the internal erase+program cycle.
 *
 * Data pins must already be set to output (flash_data_dir_out).
 */
static void flash_write_page(uint32_t page_num, const uint8_t *data) {
    uint32_t base = page_num * PAGE_SIZE;

    /* Per-page SDP unlock: AA→5555, 55→2AAA, A0→5555 (fast, µs gaps) */
    flash_unlock_for_write();

    /* Page load: CE_N held low through all 256 WE_N pulses */
    gpio_put(CE_N_PIN, 0);

    for (uint32_t i = 0; i < PAGE_SIZE; i++) {
        flash_set_address(base | i);
        flash_set_data_out(data[i]);
        sleep_us(1);            /* tAS + tDS setup */
        gpio_put(WE_N_PIN, 0);
        sleep_us(1);            /* tWP >= 100 ns */
        gpio_put(WE_N_PIN, 1);
        sleep_us(1);            /* tWPH */
    }

    gpio_put(CE_N_PIN, 1);      /* rising edge triggers internal write */
    sleep_ms(15);               /* tWC max = 10 ms + 5 ms margin */
}

/* -------------------------------------------------------------------------
 * GPIO initialisation
 * ---------------------------------------------------------------------- */

static void flash_gpio_init(void) {
    /* All flash bus pins start high-Z (input, no pulls).
     * They are driven only while the bus is acquired (flash_bus_acquire).
     * External pull-ups on WE_N/OE_N/CE_N keep those lines safely inactive. */
    for (int i = 0; i < 19; i++) {
        gpio_init(ADDR_PINS[i]);
        gpio_set_dir(ADDR_PINS[i], GPIO_IN);
        gpio_disable_pulls(ADDR_PINS[i]);
    }
    for (int i = 0; i < 8; i++) {
        gpio_init(DATA_PINS[i]);
        gpio_set_dir(DATA_PINS[i], GPIO_IN);
        gpio_disable_pulls(DATA_PINS[i]);
    }
    gpio_init(WE_N_PIN); gpio_set_dir(WE_N_PIN, GPIO_IN); gpio_disable_pulls(WE_N_PIN);
    gpio_init(OE_N_PIN); gpio_set_dir(OE_N_PIN, GPIO_IN); gpio_disable_pulls(OE_N_PIN);
    gpio_init(CE_N_PIN); gpio_set_dir(CE_N_PIN, GPIO_IN); gpio_disable_pulls(CE_N_PIN);

    /* DC_BUS: output, low when idle */
    gpio_init(DC_BUS_PIN); gpio_set_dir(DC_BUS_PIN, GPIO_OUT); gpio_put(DC_BUS_PIN, 0);
}

/* -------------------------------------------------------------------------
 * Protocol helpers
 * ---------------------------------------------------------------------- */

/* Read one byte from USB CDC; timeout in microseconds. Returns -1 on timeout. */
static int recv_byte_timeout(uint32_t timeout_us) {
    return getchar_timeout_us(timeout_us);
}

/*
 * Receive exactly 'len' bytes into 'buf'.
 * Allows up to 5 s per byte (USB CDC latency is well under 1 ms in practice).
 * Returns false on timeout.
 */
static bool recv_bytes(uint8_t *buf, size_t len) {
    for (size_t i = 0; i < len; i++) {
        heartbeat_update();
        int c = recv_byte_timeout(5000000u);
        if (c < 0) {
            return false;
        }
        buf[i] = (uint8_t)c;
    }
    return true;
}

/* Send 'len' raw bytes (binary-safe). */
static void send_bytes(const uint8_t *buf, size_t len) {
    for (size_t i = 0; i < len; i++) {
        putchar_raw((int)buf[i]);
    }
    stdio_flush();
}

/* Send a text response line. */
static void send_line(const char *msg) {
    printf("%s\n", msg);
    stdio_flush();
}

/* Read a text line from stdin (strips \r\n).  Non-blocking: returns false
 * if no complete line is available yet (call again from main loop). */
static bool readline_nonblocking(char *buf, size_t bufsize, size_t *len) {
    int c = recv_byte_timeout(0); /* non-blocking */
    if (c < 0) {
        return false; /* no data */
    }
    if (c == '\r') {
        return false; /* ignore CR */
    }
    if (c == '\n') {
        buf[*len] = '\0';
        return *len > 0; /* complete line */
    }
    if (*len < bufsize - 1) {
        buf[(*len)++] = (char)c;
    }
    return false;
}

/* -------------------------------------------------------------------------
 * Command handlers
 * ---------------------------------------------------------------------- */

static uint8_t chunk_buf[CHUNK_SIZE];

/* FLASH <size> : program flash with binary data from host */
static void cmd_flash(uint32_t total_size) {
    if (total_size == 0 || total_size > FLASH_SIZE) {
        send_line("ERR Invalid size");
        return;
    }

    send_line("OK");

    flash_bus_acquire();
    flash_data_dir_out();
    /* No global SDP disable — flash_write_page sends per-page 3-byte unlock */

    uint32_t offset = 0;
    bool ok = true;

    while (offset < total_size) {
        uint32_t chunk = total_size - offset;
        if (chunk > CHUNK_SIZE) chunk = CHUNK_SIZE;

        /* Pad last chunk to full CHUNK_SIZE so we always receive complete chunks */
        uint32_t recv_size = chunk;
        if (recv_size < CHUNK_SIZE && (total_size % CHUNK_SIZE) != 0) {
            /* host pads with 0xFF */
            recv_size = CHUNK_SIZE;
        }

        if (!recv_bytes(chunk_buf, recv_size)) {
            send_line("ERR Timeout");
            ok = false;
            break;
        }

        /* Write pages within this chunk */
        uint32_t pages = recv_size / PAGE_SIZE;
        for (uint32_t p = 0; p < pages; p++) {
            uint32_t page_num = (offset / PAGE_SIZE) + p;
            flash_write_page(page_num, &chunk_buf[p * PAGE_SIZE]);
        }

        offset += chunk;
        send_line("ACK");
    }

    flash_bus_release();

    if (ok) {
        send_line("DONE");
    }
}

/* VERIFY <size> : compare host data with flash contents */
static void cmd_verify(uint32_t total_size) {
    if (total_size == 0 || total_size > FLASH_SIZE) {
        send_line("ERR Invalid size");
        return;
    }

    send_line("OK");

    flash_bus_acquire();
    flash_data_dir_in();

    uint32_t offset = 0;
    bool ok = true;

    while (offset < total_size && ok) {
        uint32_t chunk = total_size - offset;
        if (chunk > CHUNK_SIZE) chunk = CHUNK_SIZE;

        uint32_t recv_size = chunk;
        if (recv_size < CHUNK_SIZE && (total_size % CHUNK_SIZE) != 0) {
            recv_size = CHUNK_SIZE;
        }

        if (!recv_bytes(chunk_buf, recv_size)) {
            send_line("ERR Timeout");
            ok = false;
            break;
        }

        /* Compare byte by byte */
        for (uint32_t i = 0; i < chunk; i++) {
            uint8_t got = flash_read_byte(offset + i);
            if (got != chunk_buf[i]) {
                char msg[48];
                snprintf(msg, sizeof(msg), "ERR %lu", (unsigned long)(offset + i));
                send_line(msg);
                ok = false;
                break;
            }
        }

        if (ok) {
            offset += chunk;
            send_line("ACK");
        }
    }

    flash_bus_release();

    if (ok) {
        send_line("DONE");
    }
}

/* DUMP : send entire flash contents to host */
static void cmd_dump(void) {
    char size_msg[32];
    snprintf(size_msg, sizeof(size_msg), "SIZE %u", (unsigned)FLASH_SIZE);
    send_line(size_msg);

    flash_bus_acquire();
    flash_data_dir_in();

    uint32_t offset = 0;

    while (offset < FLASH_SIZE) {
        uint32_t chunk = FLASH_SIZE - offset;
        if (chunk > CHUNK_SIZE) chunk = CHUNK_SIZE;

        /* Read chunk from flash */
        for (uint32_t i = 0; i < chunk; i++) {
            chunk_buf[i] = flash_read_byte(offset + i);
            heartbeat_update();
        }

        send_bytes(chunk_buf, chunk);

        /* Wait for host ACK before sending next chunk */
        /* Read "ACK\n" (4 bytes) */
        uint8_t ack[8];
        size_t ack_len = 0;
        bool got_ack = false;
        for (int t = 0; t < 8; t++) {
            int c = recv_byte_timeout(5000000u);
            if (c < 0) break;
            if (c == '\n') { got_ack = true; break; }
            if (ack_len < sizeof(ack) - 1) ack[ack_len++] = (uint8_t)c;
        }

        if (!got_ack) {
            flash_bus_release();
            send_line("ERR Timeout waiting for ACK");
            return;
        }

        offset += chunk;
    }

    flash_bus_release();
    send_line("DONE");
}

/* -------------------------------------------------------------------------
 * Command dispatcher
 * ---------------------------------------------------------------------- */

static void handle_command(const char *cmd) {
    if (strcmp(cmd, "VER") == 0) {
        printf("OK %s\n", FIRMWARE_VERSION);
        stdio_flush();

    } else if (strcmp(cmd, "BOOT") == 0) {
        send_line("OK");
        sleep_ms(100);
        reset_usb_boot(0, 0);

    } else if (strncmp(cmd, "FLASH ", 6) == 0) {
        uint32_t size = (uint32_t)atol(cmd + 6);
        cmd_flash(size);

    } else if (strncmp(cmd, "VERIFY ", 7) == 0) {
        uint32_t size = (uint32_t)atol(cmd + 7);
        cmd_verify(size);

    } else if (strcmp(cmd, "DUMP") == 0) {
        cmd_dump();

    } else {
        send_line("ERR Unknown command");
    }
}

/* -------------------------------------------------------------------------
 * Main
 * ---------------------------------------------------------------------- */

int main(void) {
    stdio_init_all();

    /* LED0: on while firmware is running */
    gpio_init(LED0_PIN);
    gpio_set_dir(LED0_PIN, GPIO_OUT);
    gpio_put(LED0_PIN, 1);

    /* LED1: 2 Hz heartbeat */
    gpio_init(LED1_PIN);
    gpio_set_dir(LED1_PIN, GPIO_OUT);
    gpio_put(LED1_PIN, 0);
    led1_next = make_timeout_time_ms(500);

    /* Initialise flash bus GPIO (all inactive/input) */
    flash_gpio_init();

    /* Wait for USB host to connect */
    while (!stdio_usb_connected()) {
        heartbeat_update();
        sleep_ms(10);
    }

    /* Main command loop */
    char cmd_buf[CMD_BUF_SIZE];
    size_t cmd_len = 0;

    while (true) {
        heartbeat_update();

        if (readline_nonblocking(cmd_buf, CMD_BUF_SIZE, &cmd_len)) {
            handle_command(cmd_buf);
            cmd_len = 0;
        }
    }

    return 0;
}

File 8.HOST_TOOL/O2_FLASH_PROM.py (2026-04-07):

#!/usr/bin/env python3
"""
O2_FLASH_PROM.py - Host-side tool for O2 PROM ISP firmware

Usage:
  O2_FLASH_PROM.py --port <port> --flash <file.bin> [--verify]
  O2_FLASH_PROM.py --port <port> --dump <file.bin>
  O2_FLASH_PROM.py --port <port> --version
  O2_FLASH_PROM.py --port <port> --boot
  O2_FLASH_PROM.py --port <port> --setenv <key> <value>
  O2_FLASH_PROM.py --port <port> --unsetenv <key>
  O2_FLASH_PROM.py --port <port> --resetenv

  --port   Serial port: e.g. COM32 (Windows) or /dev/ttyUSB0 (Linux)

Requires: pyserial  (pip install pyserial)
"""

import argparse
import sys
import os
import serial
import serial.tools.list_ports
import time
import struct

# ─────────────────────────────────────────────────────────────────────────────
# Constants
# ─────────────────────────────────────────────────────────────────────────────

FLASH_SIZE  = 512 * 1024   # AT29C040A: 512 KB
CHUNK_SIZE  = 4096         # Must match firmware CHUNK_SIZE
BAUD_RATE   = 115200       # Ignored for USB CDC, but required by pyserial
CMD_TIMEOUT = 10           # Seconds to wait for a text response line
DATA_TIMEOUT = 60          # Seconds allowed for a full chunk transfer

# ─────────────────────────────────────────────────────────────────────────────
# Serial helpers
# ─────────────────────────────────────────────────────────────────────────────

def open_port(port: str) -> serial.Serial:
    """Open the CDC serial port."""
    try:
        ser = serial.Serial(
            port,
            baudrate=BAUD_RATE,
            timeout=CMD_TIMEOUT,
            write_timeout=DATA_TIMEOUT,
        )
        # Flush any stale data
        ser.reset_input_buffer()
        ser.reset_output_buffer()
        return ser
    except serial.SerialException as e:
        die(f"Cannot open port '{port}': {e}")


def send_cmd(ser: serial.Serial, cmd: str) -> None:
    """Send a text command (adds newline)."""
    ser.write((cmd + "\n").encode())
    ser.flush()


def read_line(ser: serial.Serial) -> str:
    """Read one response line (strips \\r\\n). Raises on timeout."""
    line = ser.readline()
    if not line:
        die("Timeout waiting for response from firmware")
    return line.decode(errors="replace").strip()


def expect_ok(ser: serial.Serial, context: str = "") -> None:
    """Read a line and die if it is not 'OK' (or 'OK ...')."""
    resp = read_line(ser)
    if not resp.startswith("OK"):
        die(f"Unexpected response{' ' + context if context else ''}: {resp}")


# ─────────────────────────────────────────────────────────────────────────────
# Utility
# ─────────────────────────────────────────────────────────────────────────────

def die(msg: str) -> None:
    print(f"ERROR: {msg}", file=sys.stderr)
    sys.exit(1)


def progress(label: str, done: int, total: int) -> None:
    pct = done * 100 // total
    bar_len = 40
    filled = bar_len * done // total
    bar = "#" * filled + "-" * (bar_len - filled)
    print(f"\r{label}: [{bar}] {pct:3d}%", end="", flush=True)


def pad_to_chunk(data: bytes, chunk: int = CHUNK_SIZE) -> bytes:
    """Pad data with 0xFF so its length is a multiple of chunk."""
    rem = len(data) % chunk
    if rem:
        data += b"\xff" * (chunk - rem)
    return data


# ─────────────────────────────────────────────────────────────────────────────
# Command implementations
# ─────────────────────────────────────────────────────────────────────────────

def cmd_version(ser: serial.Serial) -> None:
    send_cmd(ser, "VER")
    resp = read_line(ser)
    if resp.startswith("OK "):
        print(f"Firmware version: {resp[3:]}")
    elif resp == "OK":
        print("Firmware version: (unknown)")
    else:
        die(f"Unexpected response: {resp}")


def cmd_boot(ser: serial.Serial) -> None:
    send_cmd(ser, "BOOT")
    resp = read_line(ser)
    if resp.startswith("OK"):
        print("MCU is rebooting into BOOTSEL (UF2) mode.")
        print("A USB mass-storage drive will appear — copy your .uf2 file there.")
    else:
        die(f"Unexpected response: {resp}")


def cmd_flash(ser: serial.Serial, filename: str, verify: bool = False) -> None:
    # Read file
    if not os.path.isfile(filename):
        die(f"File not found: {filename}")
    with open(filename, "rb") as f:
        raw = f.read()

    if len(raw) > FLASH_SIZE:
        die(f"File size {len(raw):,} bytes exceeds flash size {FLASH_SIZE:,} bytes")

    original_size = len(raw)
    # Always pad to full FLASH_SIZE with 0xFF so the entire chip is overwritten,
    # leaving no residual data from a previous image beyond the file boundary.
    data = raw + b"\xff" * (FLASH_SIZE - len(raw))
    total_chunks = FLASH_SIZE // CHUNK_SIZE   # always 128

    print(f"File : {filename}  ({original_size:,} bytes)")
    print(f"Flash: {FLASH_SIZE:,} bytes  |  Chunks: {total_chunks} × {CHUNK_SIZE} bytes")

    # ── Flash phase ──────────────────────────────────────────────────────────
    flash_firmware(ser, data)

    # ── Verify phase (optional) ──────────────────────────────────────────────
    if verify:
        cmd_verify_only(ser, data, original_size)


def cmd_verify_only(ser: serial.Serial, data: bytes, original_size: int) -> None:
    """Send VERIFY command and compare host data with flash contents."""
    # data is already padded to FLASH_SIZE; verify the full chip
    total_chunks = FLASH_SIZE // CHUNK_SIZE

    print("\nVerifying...")
    send_cmd(ser, f"VERIFY {FLASH_SIZE}")
    expect_ok(ser, "after VERIFY command")

    for i in range(total_chunks):
        chunk = data[i * CHUNK_SIZE:(i + 1) * CHUNK_SIZE]
        ser.write(chunk)
        ser.flush()

        resp = read_line(ser)
        if resp.startswith("ERR"):
            print()
            # ERR <offset>
            parts = resp.split()
            offset_str = parts[1] if len(parts) > 1 else "?"
            die(f"Mismatch at flash offset {offset_str}")
        elif resp != "ACK":
            print()
            die(f"Expected ACK after verify chunk {i}, got: {resp}")
        progress("Verifying", i + 1, total_chunks)

    print()
    resp = read_line(ser)
    if resp != "DONE":
        die(f"Verify did not complete cleanly: {resp}")
    print("Verify passed — flash contents match file.")


def cmd_dump(ser: serial.Serial, filename: str) -> None:
    print(f"Dumping {FLASH_SIZE:,} bytes to: {filename}")
    
    # Dump the firmware
    received = dump_firmware(ser)
    
    # Save to file
    with open(filename, "wb") as f:
        f.write(received)
    print(f"Dump complete. Saved {len(received):,} bytes to '{filename}'.")
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

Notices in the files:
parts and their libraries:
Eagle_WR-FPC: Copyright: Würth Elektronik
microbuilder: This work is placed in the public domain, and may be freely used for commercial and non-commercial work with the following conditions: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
